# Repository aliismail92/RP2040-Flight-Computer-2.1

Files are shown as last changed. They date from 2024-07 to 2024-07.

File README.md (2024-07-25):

# RP2040-Flight-Computer-2.1
This is a custom drone flight computer based on RP2040. The KiCad files are available in addition to the production files to be produced by JLC PCB.

The Flight computer has the following sensors:
  - MPU 6050 Inertia sensor
  - LSM303 digital compass and accelerometer sensor
  - BMP280 pressure sensor

Specific features:

  - Uses usb Type C.
  - SD-card connector at the bottom of the board
  - Two uart connectors for the Radio controller (tagged IBUS) and another for GPS (tagged GPS)
  - Broken GPIOs for NRF24L01 for telemetry with proper pin locations
  - Buzzer

The two I2C ports connected to the MPU6050, BMP280, and LSM303 sensors have the pins exposed for debugging purposes.

The board was produced and assembled by JLCPCB and is working.


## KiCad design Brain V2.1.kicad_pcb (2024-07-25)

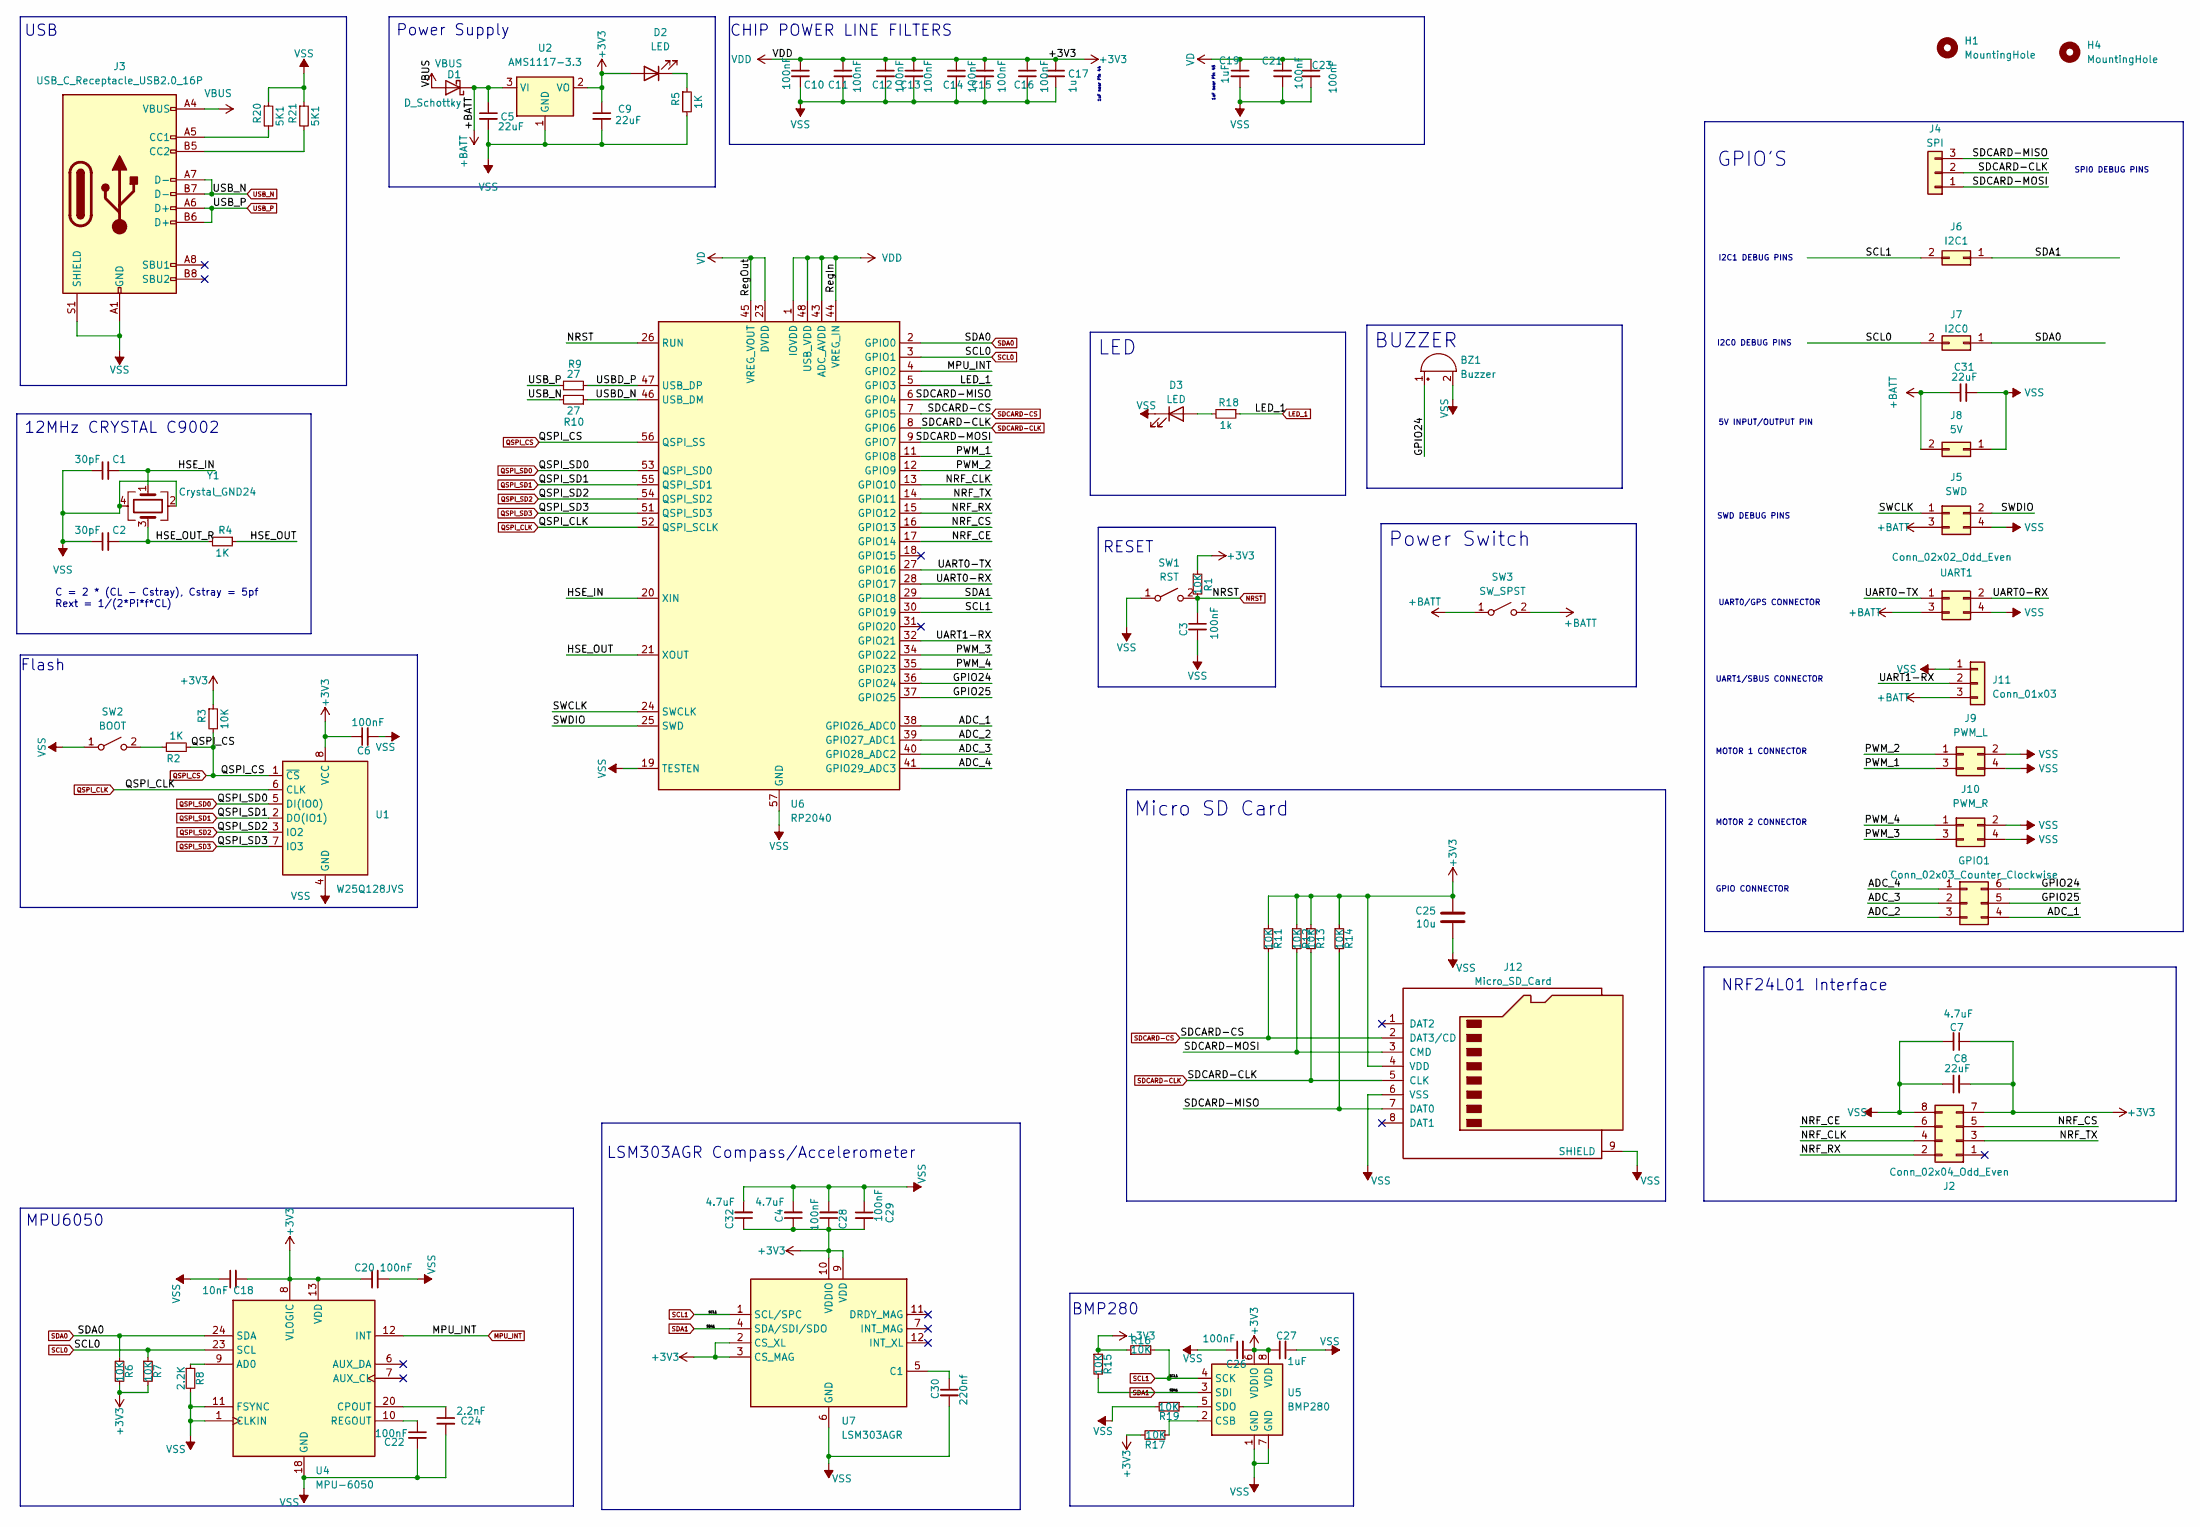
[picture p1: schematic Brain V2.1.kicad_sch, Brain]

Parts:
BZ1: Buzzer; Buzzer_12x9.5RM7.6
C1, C2: 30pF; C_0402_1005Metric
C3, C6, C10, C11, C12, C13, C14, C15, C16, C20, C21, C22, C23, C26, C28, C29: 100nF; C_0402_1005Metric
C4, C7, C32: 4.7uF; C_0603_1608Metric
C5, C8, C9, C31: 22uF; C_0603_1608Metric
C17: 1u; C_0402_1005Metric_Pad0.74x0.62mm_HandSolder
C18: 10nF; C_0402_1005Metric
C19: 1uF; C_0402_1005Metric_Pad0.74x0.62mm_HandSolder
C24: 2.2nF; C_0603_1608Metric
C25: 10u; C_0603_1608Metric
C27: 1uF; C_0402_1005Metric
C30: 220nf; C_0402_1005Metric
D1: D_Schottky; D_SMA
D2, D3: LED; LED_0603_1608Metric
GPIO1: Conn_02x03_Counter_Clockwise; PinHeader_2x03_P2.54mm_Vertical
H1, H4: MountingHole; MountingHole_4.3mm_M4
J2: Conn_02x04_Odd_Even; PinHeader_2x04_P2.54mm_Vertical
J3: USB_C_Receptacle_USB2.0_16P; USB_C_Receptacle_G-Switch_GT-USB-7010ASV
J4: SPI; PinHeader_1x03_P2.54mm_Vertical
J5: SWD; PinHeader_2x02_P2.54mm_Vertical
J6: I2C1; PinHeader_2x01_P2.54mm_Vertical
J7: I2C0; PinHeader_2x01_P2.54mm_Vertical
J8: 5V; PinHeader_2x01_P2.54mm_Vertical
J9: PWM_L; PinHeader_2x02_P2.54mm_Vertical
J10: PWM_R; PinHeader_2x02_P2.54mm_Vertical
J11: Conn_01x03; JST_XH_B3B-XH-AM_1x03_P2.50mm_Vertical
J12: Micro_SD_Card; microSD_HC_Molex_104031-0811
R1, R3, R6, R7, R11, R12, R13, R14, R15, R16, R17, R19: 10K; R_0402_1005Metric
R2, R4: 1K; R_0402_1005Metric
R5: 1K; R_0603_1608Metric
R8: 2.2K; R_0402_1005Metric
R9, R10: 27; R_0603_1608Metric
R18: 1k; R_0603_1608Metric
R20, R21: 5K1; R_0603_1608Metric
SW1: RST; SW_SPST_TL3342
SW2: BOOT; SW_SPST_TL3342
SW3: SW_SPST; SW_DIP_SPSTx01_Slide_9.78x4.72mm_W7.62mm_P2.54mm
U1: W25Q128JVS; SOIC-8_5.23x5.23mm_P1.27mm
U2: AMS1117-3.3; SOT-223-3_TabPin2
U4: MPU-6050; InvenSense_QFN-24_4x4mm_P0.5mm_NoMask
U5: BMP280; Bosch_LGA-8_2x2.5mm_P0.65mm_ClockwisePinNumbering
U6: RP2040; QFN-56-1EP_7x7mm_P0.4mm_EP4x4mm_ThermalVias
U7: LSM303AGR; LGA-12_2x2mm_P0.5mm
UART1: Conn_02x02_Odd_Even; JST_XH_B4B-XH-A_1x04_P2.50mm_Vertical
Y1: Crystal_GND24; Crystal_SMD_3225-4Pin_3.2x2.5mm

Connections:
+3V3: C4.1, C6.1, C7.1, C8.2, C9.1, C10.1, C11.1, C12.1, C13.1, C14.1, C15.1, C16.1, C17.1, C18.2, C20.2, C25.1, C26.2, C27.2, C28.1, C29.2, C32.1, D2.2 (A), J2.7, J12.4 (VDD), R1.1, R3.1, R6.2, R7.2, R11.1, R12.1, R13.1, R14.1, R15.1, R16.1, R17.2, U1.8 (VCC), U2.2 (VO), U4.8 (VLOGIC), U4.13 (VDD), U5.6 (VDDIO), U5.8 (VDD), U6.1 (IOVDD), U6.10 (IOVDD), U6.22 (IOVDD), U6.33 (IOVDD), U6.42 (IOVDD), U6.43 (ADC_AVDD), U6.44 (VREG_IN), U6.48 (USB_VDD), U6.49 (IOVDD), U7.2 (CS_XL), U7.3 (CS_MAG), U7.9 (VDD), U7.10 (VDDIO)
+BATT: C5.1, C31.1, D1.1 (K), J5.3, J8.2, J11.3, SW3.1 (A), SW3.2 (B), U2.3 (VI), UART1.3
/ADC_1: GPIO1.4, U6.38 (GPIO26_ADC0)
/ADC_2: GPIO1.3, U6.39 (GPIO27_ADC1)
/ADC_3: GPIO1.2, U6.40 (GPIO28_ADC2)
/ADC_4: GPIO1.1, U6.41 (GPIO29_ADC3)
/GPIO24: BZ1.1 (+), GPIO1.6, U6.36 (GPIO24)
/GPIO25: GPIO1.5, U6.37 (GPIO25)
/HSE_IN: C1.2, U6.20 (XIN), Y1.1
/HSE_OUT: R4.1, U6.21 (XOUT)
/HSE_OUT_R: C2.2, R4.2, Y1.3
/NRF_CE: J2.6, U6.17 (GPIO14)
/NRF_CLK: J2.4, U6.13 (GPIO10)
/NRF_CS: J2.5, U6.16 (GPIO13)
/NRF_RX: J2.2, U6.15 (GPIO12)
/NRF_TX: J2.3, U6.14 (GPIO11)
/PWM_1: J9.3, U6.11 (GPIO8)
/PWM_2: J9.1, U6.12 (GPIO9)
/PWM_3: J10.3, U6.34 (GPIO22)
/PWM_4: J10.1, U6.35 (GPIO23)
/SDCARD-MISO: J4.3, J12.7 (DAT0), R14.2, U6.6 (GPIO4)
/SDCARD-MOSI: J4.1, J12.3 (CMD), R12.2, U6.9 (GPIO7)
/SWCLK: J5.1, U6.24 (SWCLK)
/SWDIO: J5.2, U6.25 (SWD)
/UART0-RX: U6.28 (GPIO17), UART1.2
/UART0-TX: U6.27 (GPIO16), UART1.1
/UART1-RX: J11.2, U6.32 (GPIO21)
/USBD_N: R10.1, U6.46 (USB_DM)
/USBD_P: R9.1, U6.47 (USB_DP)
LED_1: R18.1, U6.5 (GPIO3)
MPU_INT: U4.12 (INT), U6.4 (GPIO2)
NRST: C3.1, R1.2, SW1.2 (B), U6.26 (RUN)
unnamed: D2.1 (K), R5.1
unnamed: D3.2 (A), R18.2
unnamed: J3.A5 (CC1), R20.2
unnamed: J3.B5 (CC2), R21.2
unnamed: R2.1, SW2.2 (B)
unnamed: R8.1, U4.9 (AD0)
unnamed: C24.1, U4.20 (CPOUT)
unnamed: C22.1, U4.10 (REGOUT)
unnamed: R17.1, U5.2 (CSB)
unnamed: R19.1, U5.5 (SDO)
unnamed: C30.1, U7.5 (C1)
QSPI_CLK: U1.6 (CLK), U6.52 (QSPI_SCLK)
QSPI_CS: R2.2, R3.2, U1.1 (~CS), U6.56 (QSPI_SS)
QSPI_SD0: U1.5 (DI(IO0)), U6.53 (QSPI_SD0)
QSPI_SD1: U1.2 (DO(IO1)), U6.55 (QSPI_SD1)
QSPI_SD2: U1.3 (IO2), U6.54 (QSPI_SD2)
QSPI_SD3: U1.7 (IO3), U6.51 (QSPI_SD3)
SCL0: J7.2, R7.1, U4.23 (SCL), U6.3 (GPIO1)
SCL1: J6.2, R16.2, U5.4 (SCK), U6.30 (GPIO19), U7.1 (SCL/SPC)
SDA0: J7.1, R6.1, U4.24 (SDA), U6.2 (GPIO0)
SDA1: J6.1, R15.2, U5.3 (SDI), U6.29 (GPIO18), U7.4 (SDA/SDI/SDO)
SDCARD-CLK: J4.2, J12.5 (CLK), R13.2, U6.8 (GPIO6)
SDCARD-CS: J12.2 (DAT3/CD), R11.2, U6.7 (GPIO5)
USB_N: J3.A7 (D-), J3.B7 (D-), R10.2
USB_P: J3.A6 (D+), J3.B6 (D+), R9.2
VBUS: D1.2 (A), J3.A4 (VBUS), J3.A9 (VBUS), J3.B4 (VBUS), J3.B9 (VBUS)
VD: C19.1, C21.1, C23.1, U6.23 (DVDD), U6.45 (VREG_VOUT), U6.50 (DVDD)
VSS: BZ1.2 (-), C1.1, C2.1, C3.2, C4.2, C5.2, C6.2, C7.2, C8.1, C9.2, C10.2, C11.2, C12.2, C13.2, C14.2, C15.2, C16.2, C17.2, C18.1, C19.2, C20.1, C21.2, C22.2, C23.2, C24.2, C25.2, C26.1, C27.1, C28.2, C29.1, C30.2, C31.2, C32.2, D3.1 (K), J2.8, J3.A1 (GND), J3.A12 (GND), J3.B1 (GND), J3.B12 (GND), J3.S1 (SHIELD), J5.4, J8.1, J9.2, J9.4, J10.2, J10.4, J11.1, J12.6 (VSS), J12.9 (SHIELD), R5.2, R8.2, R19.2, R20.1, R21.1, SW1.1 (A), SW2.1 (A), U1.4 (GND), U2.1 (GND), U4.1 (CLKIN), U4.11 (FSYNC), U4.18 (GND), U5.1 (GND), U5.7 (GND), U6.19 (TESTEN), U6.57 (GND), U7.6 (GND), U7.8 (GND), UART1.4, Y1.2, Y1.4

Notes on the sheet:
RESET
GPIO CONNECTOR
GPIO'S
UART1/SBUS CONNECTOR
SWD DEBUG PINS
5V INPUT/OUTPUT PIN
1uF near Pin 45
MPU6050
I2C0 DEBUG PINS
CHIP POWER LINE FILTERS
BMP280
12MHz CRYSTAL C9002
LED
Micro SD Card
SPI0 DEBUG PINS
LSM303AGR Compass/Accelerometer
NRF24L01 Interface
Flash
MOTOR 1 CONNECTOR
BUZZER
I2C1 DEBUG PINS
UART0/GPS CONNECTOR
C = 2 * (CL - Cstray), Cstray = 5pf Rext = 1/(2*Pi*f*CL)
MOTOR 2 CONNECTOR
Power Supply
USB
Power Switch
1uF near Pin 44

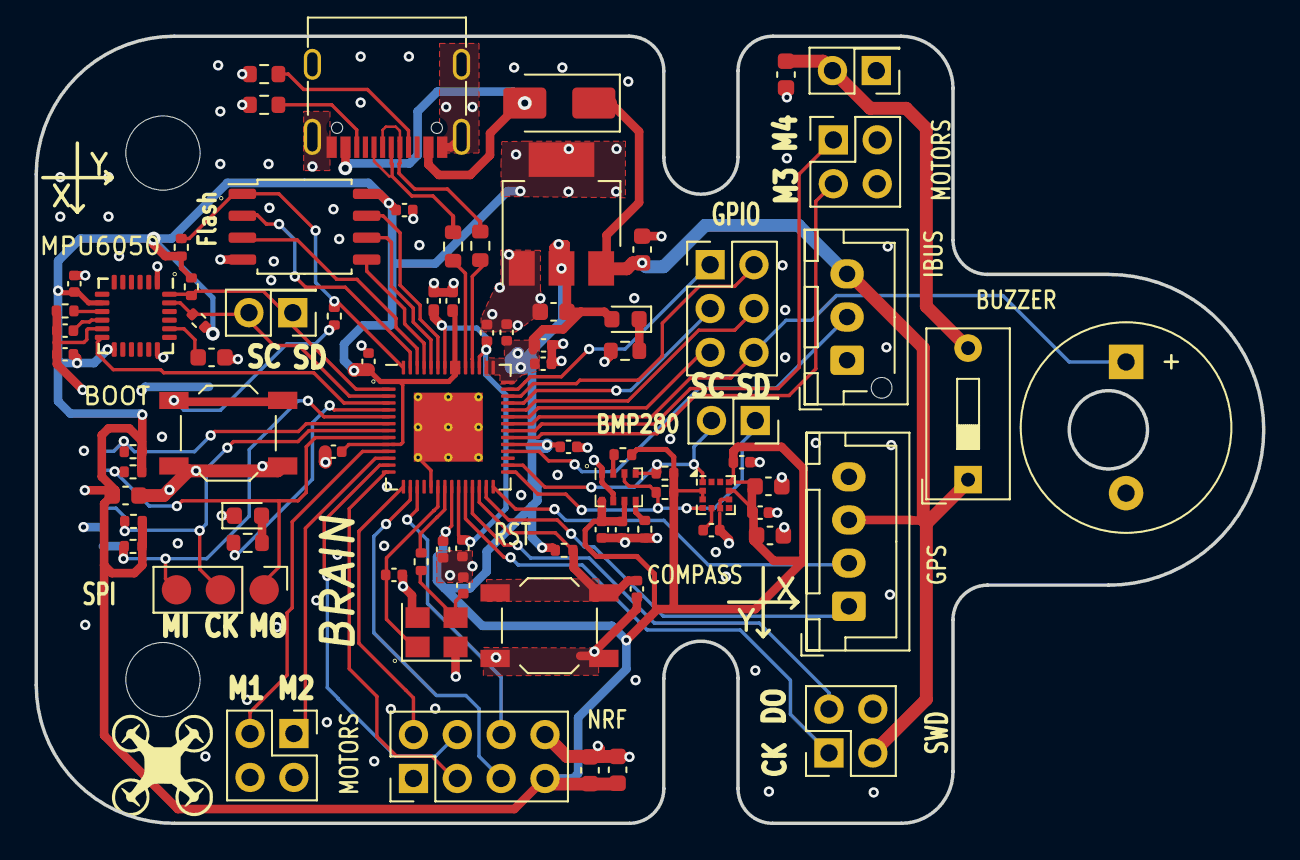
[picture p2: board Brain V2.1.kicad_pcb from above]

Board: 4 copper layers, 71.1 x 45.6 mm, 82 parts (1 on the bottom side), 60 nets.
